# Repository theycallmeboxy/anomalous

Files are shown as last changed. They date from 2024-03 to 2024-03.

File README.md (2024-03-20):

# Anomalous Keyboard

## Features

- Integrated STM32 Microcontroller
  
- 42 Key Alice-ish Ortho Layout

- Red Dragon Low Profile Switches

- Solder Only

## Repository Contents

- `pcb/`: KiCAD and production files (bom is missing part numbers)

## Status

- Prototype 1 PCBs ordered 3/15/2024
- Prototype 1 PCBs received 3/20/2024

**DISCLAIMER: I'm not a doctor.  This is not medical advice.  I'm also only a network engineer.  You assume all liability in using or reproducing these files.**

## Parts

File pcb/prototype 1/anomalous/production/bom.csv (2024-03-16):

Designator | Footprint | Quantity | Value | LCSC Part #
BOOT1, RST1 | SW_SPST_TL3342 | 2 | SW_SPST
C1, C3, C4, C5, C6, C7, C8 | 0402 | 7 | 100nF | C307331
C10, C9 | 0402 | 2 | 1uF | C307331
C2 | 0603 | 1 | 10uF | C307331
D1, D10, D11, D12, D13, D14, D15, D16, D17, D18, D19, D2, D20, D21, D22, D23, D24, D25, D26, D27, D28, D29, D3, D30, D31, D32, D33, D34, D35, D36, D37, D38, D39, D4, D40, D41, D42, D5, D6, D7, D8, D9 | D_SOD-123 | 42 | D_Small
F1 | 1206 | 1 | 500mA | C135341
J1 | USB_C_Receptacle_HRO_TYPE-C-31-M-12 | 1 | USB_C_Receptacle_USB2.0
MX1, MX10, MX11, MX12, MX13, MX14, MX15, MX16, MX17, MX18, MX19, MX2, MX20, MX21, MX22, MX23, MX24, MX25, MX26, MX27, MX28, MX29, MX3, MX30, MX31, MX32, MX33, MX34, MX35, MX36, MX37, MX38, MX39, MX4, MX40, MX41, MX42, MX5, MX6, MX7, MX8, MX9 | SW_Redragon_LowProfile_PCB_1.00u-naked | 42 | MX_SW_solder
R1, R2, R3, R4 | 0402 | 4 | 5.1k
U1 | LQFP-48_7x7mm_P0.5mm | 1 | STM32F072CBT6
U2 | SOT-143 | 1 | PRTR5V0U2X | C2827688
U3 | SOT-23 | 1 | XC6206PxxxMR-Regulator_Linear | C5446

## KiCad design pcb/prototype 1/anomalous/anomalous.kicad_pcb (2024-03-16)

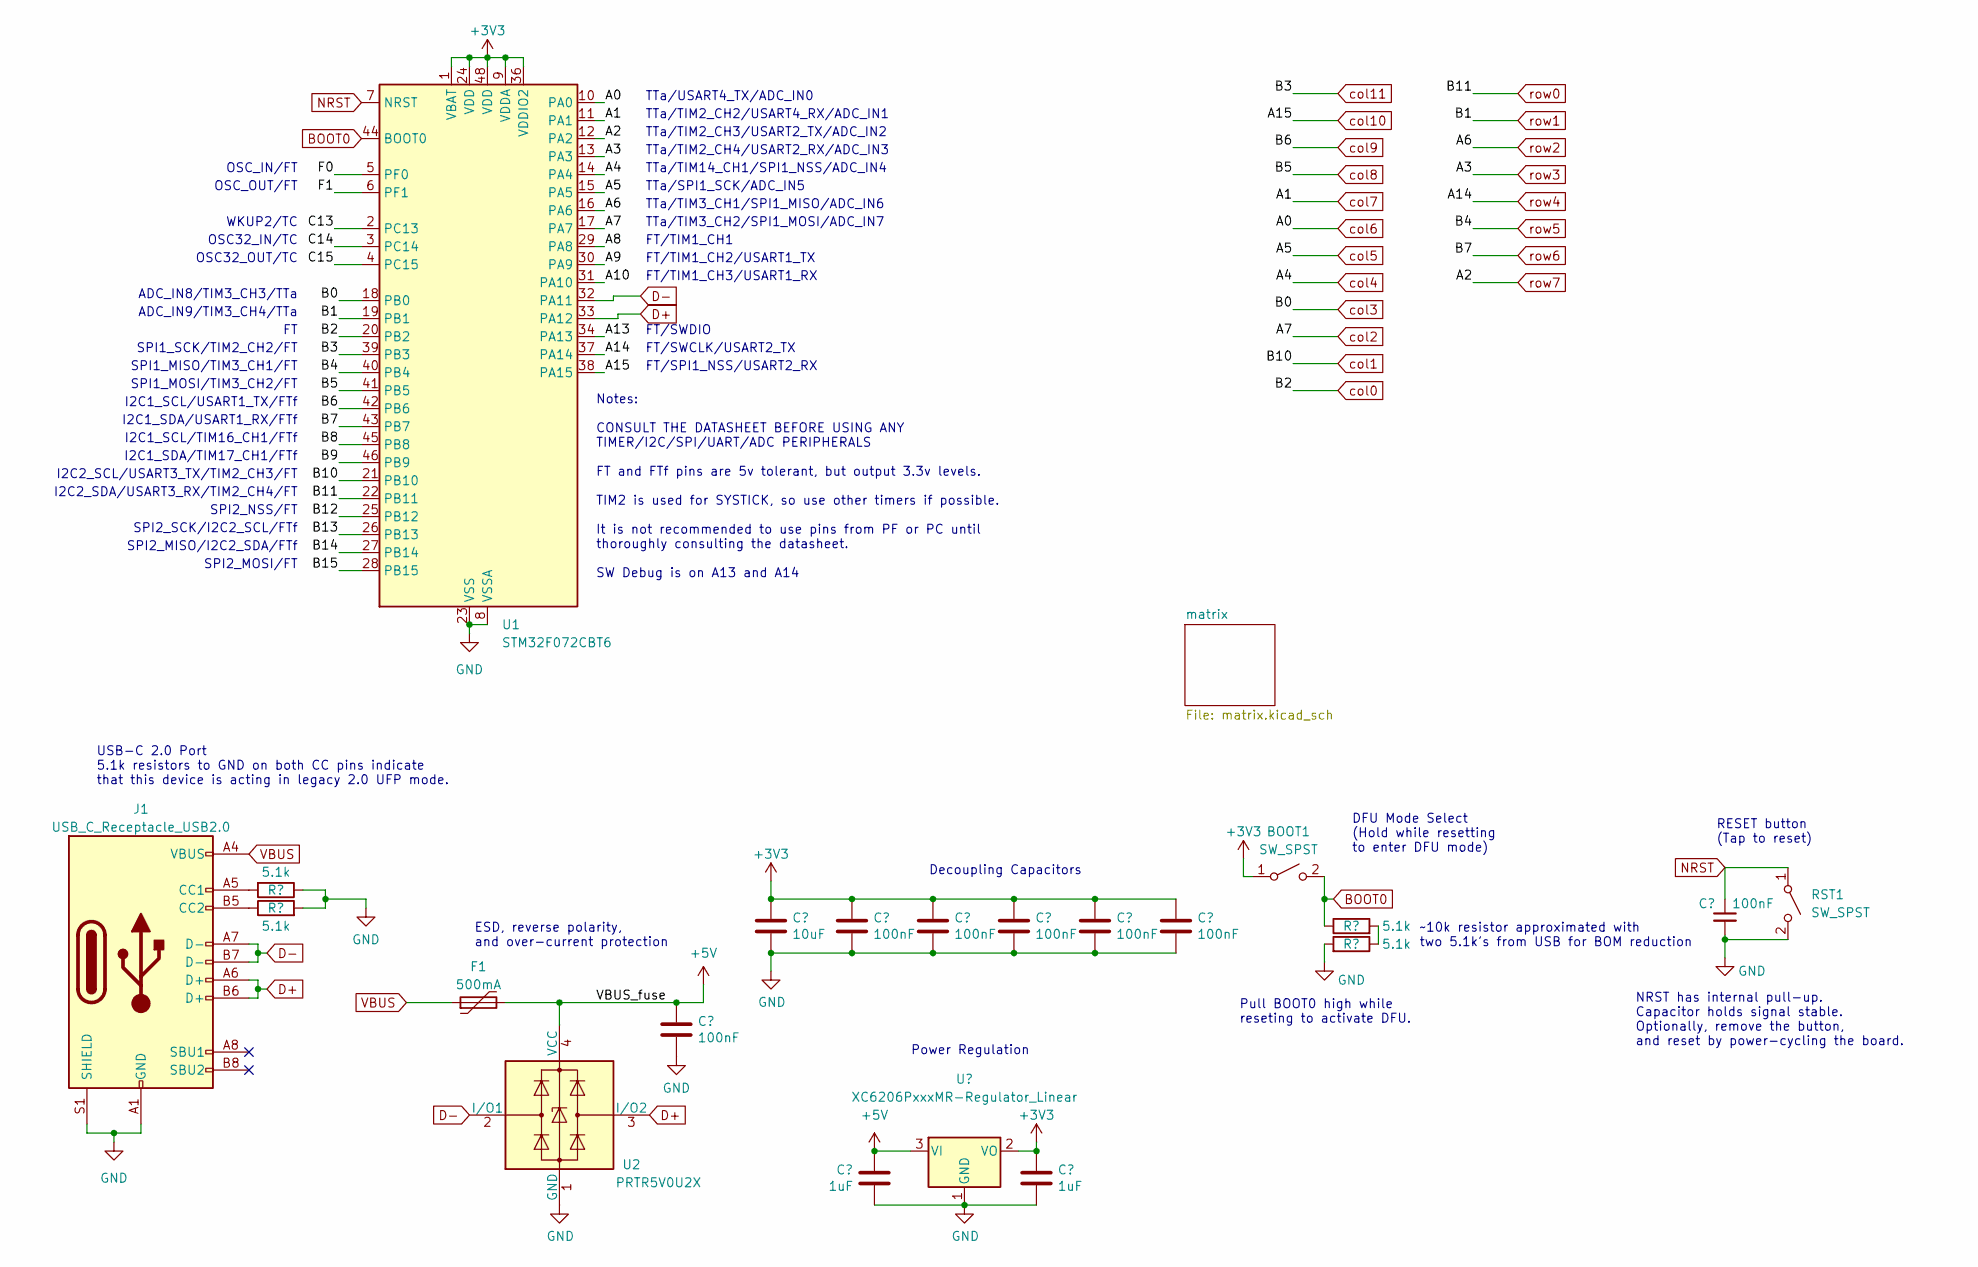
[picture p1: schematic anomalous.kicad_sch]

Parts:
BOOT1: SW_SPST; SW_SPST_TL3342
C1, C3, C4, C5, C6, C7, C8: 100nF; C_0402_1005Metric; LCSC C307331
C2: 10uF; C_0603_1608Metric; LCSC C307331
C9, C10: 1uF; C_0402_1005Metric; LCSC C307331
F1: 500mA; Fuse_1206_3216Metric; LCSC C135341
J1: USB_C_Receptacle_USB2.0; USB_C_Receptacle_HRO_TYPE-C-31-M-12; JlcRotOffset 180
R1, R2, R3, R4: 5.1k; R_0402_1005Metric
RST1: SW_SPST; SW_SPST_TL3342
U1: STM32F072CBT6; LQFP-48_7x7mm_P0.5mm; JlcRotOffset 90
U2: PRTR5V0U2X; SOT-143; LCSC C2827688
U3: XC6206PxxxMR-Regulator_Linear; SOT-23; LCSC C5446

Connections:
+3V3: BOOT1.1 (A), C2.1, C3.1, C4.1, C5.1, C6.1, C7.1, C10.1, U1.1 (VBAT), U1.9 (VDDA), U1.24 (VDD), U1.36 (VDDIO2), U1.48 (VDD), U3.2 (VO)
+5V: C8.1, C9.1, F1.2, U2.4 (VCC), U3.3 (VI)
/A8: U1.29 (PA8)
/A9: U1.30 (PA9)
/A10: U1.31 (PA10)
/A13: U1.34 (PA13)
/B8: U1.45 (PB8)
/B9: U1.46 (PB9)
/B12: U1.25 (PB12)
/B13: U1.26 (PB13)
/B14: U1.27 (PB14)
/B15: U1.28 (PB15)
/C13: U1.2 (PC13)
/C14: U1.3 (PC14)
/C15: U1.4 (PC15)
/F0: U1.5 (PF0)
/F1: U1.6 (PF1)
BOOT0: BOOT1.2 (B), R3.1, U1.44 (BOOT0)
D+: J1.A6 (D+), J1.B6 (D+), U1.33 (PA12), U2.3 (I/O2)
D-: J1.A7 (D-), J1.B7 (D-), U1.32 (PA11), U2.2 (I/O1)
GND: C1.2, C2.2, C3.2, C4.2, C5.2, C6.2, C7.2, C8.2, C9.2, C10.2, J1.A1 (GND), J1.A12 (GND), J1.B1 (GND), J1.B12 (GND), J1.S1 (SHIELD), R1.1, R2.2, R4.2, RST1.2 (B), U1.8 (VSSA), U1.23 (VSS), U1.35 (VSS), U1.47 (VSS), U2.1 (GND), U3.1 (GND)
NRST: C1.1, RST1.1 (A), U1.7 (NRST)
unnamed: J1.A5 (CC1), R1.2
unnamed: J1.B5 (CC2), R2.1
unnamed: R3.2, R4.1
VBUS: F1.1, J1.A4 (VBUS), J1.A9 (VBUS), J1.B4 (VBUS), J1.B9 (VBUS)
col0: U1.20 (PB2); also elsewhere on the board
col1: U1.21 (PB10); also elsewhere on the board
col2: U1.17 (PA7); also elsewhere on the board
col3: U1.18 (PB0); also elsewhere on the board
col4: U1.14 (PA4); also elsewhere on the board
col5: U1.15 (PA5); also elsewhere on the board
col6: U1.10 (PA0); also elsewhere on the board
col7: U1.11 (PA1); also elsewhere on the board
col8: U1.41 (PB5); also elsewhere on the board
col9: U1.42 (PB6); also elsewhere on the board
col10: U1.38 (PA15); also elsewhere on the board
col11: U1.39 (PB3); also elsewhere on the board
row0: U1.22 (PB11); also elsewhere on the board
row1: U1.19 (PB1); also elsewhere on the board
row2: U1.16 (PA6); also elsewhere on the board
row3: U1.13 (PA3); also elsewhere on the board
row4: U1.37 (PA14); also elsewhere on the board
row5: U1.40 (PB4); also elsewhere on the board
row6: U1.43 (PB7); also elsewhere on the board
row7: U1.12 (PA2); also elsewhere on the board

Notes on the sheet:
SPI1_SCK/TIM2_CH2/FT
FT/TIM1_CH1
FT/TIM1_CH3/USART1_RX
SPI2_NSS/FT
Notes: CONSULT THE DATASHEET BEFORE USING ANY TIMER/I2C/SPI/UART/ADC PERIPHERALS FT and FTf pins are 5v tolerant, but output 3.3v levels. TIM2 is used for SYSTICK, so use other timers if possible. It is not recommended to use pins from PF or PC until thoroughly consulting the datasheet. SW Debug is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
TTa/TIM2_CH4/USART2_RX/ADC_IN3
NRST has internal pull-up. Capacitor holds signal stable. Optionally, remove the button, and reset by power-cycling the board.
FT/SWDIO
Decoupling Capacitors
SPI1_MOSI/TIM3_CH2/FT
ADC_IN9/TIM3_CH4/TTa
I2C2_SCL/USART3_TX/TIM2_CH3/FT
SPI2_MISO/I2C2_SDA/FTf
FT/SWCLK/USART2_TX
I2C1_SCL/TIM16_CH1/FTf
~10k resistor approximated with two 5.1k's from USB for BOM reduction
TTa/TIM2_CH2/USART4_RX/ADC_IN1
USB-C 2.0 Port 5.1k resistors to GND on both CC pins indicate that this device is acting in legacy 2.0 UFP mode.
TTa/TIM2_CH3/USART2_TX/ADC_IN2
OSC_IN/FT
DFU Mode Select (Hold while resetting to enter DFU mode)
WKUP2/TC
I2C2_SDA/USART3_RX/TIM2_CH4/FT
ADC_IN8/TIM3_CH3/TTa
RESET button (Tap to reset)
Pull BOOT0 high while reseting to activate DFU.
I2C1_SDA/TIM17_CH1/FTf
TTa/SPI1_SCK/ADC_IN5
TTa/TIM3_CH1/SPI1_MISO/ADC_IN6
TTa/TIM3_CH2/SPI1_MOSI/ADC_IN7
OSC32_OUT/TC
FT/SPI1_NSS/USART2_RX
SPI1_MISO/TIM3_CH1/FT
OSC32_IN/TC
TTa/TIM14_CH1/SPI1_NSS/ADC_IN4
I2C1_SDA/USART1_RX/FTf
SPI2_MOSI/FT
FT/TIM1_CH2/USART1_TX
Power Regulation
SPI2_SCK/I2C2_SCL/FTf

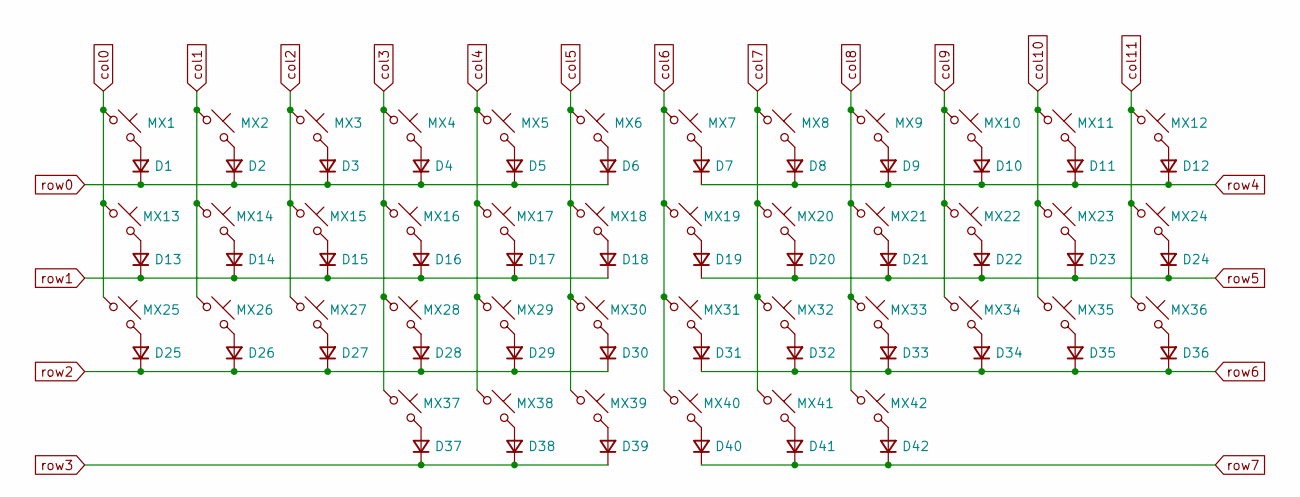
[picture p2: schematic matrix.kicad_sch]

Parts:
D1, D2, D3, D4, D5, D6, D7, D8, D9, D10, D11, D12, D13, D14, D15, D16, D17, D18, D19, D20, D21, D22, D23, D24, D25, D26, D27, D28, D29, D30, D31, D32, D33, D34, D35, D36, D37, D38, D39, D40, D41, D42: D_Small; D_SOD-123
MX1, MX2, MX3, MX4, MX5, MX6, MX7, MX8, MX9, MX10, MX11, MX12, MX13, MX14, MX15, MX16, MX17, MX18, MX19, MX20, MX21, MX22, MX23, MX24, MX25, MX26, MX27, MX28, MX29, MX30, MX31, MX32, MX33, MX34, MX35, MX36, MX37, MX38, MX39, MX40, MX41, MX42: MX_SW_solder; SW_Redragon_LowProfile_PCB_1.00u

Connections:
unnamed: D1.2 (A), MX1.2
unnamed: D2.2 (A), MX2.2
unnamed: D3.2 (A), MX3.2
unnamed: D4.2 (A), MX4.2
unnamed: D5.2 (A), MX5.2
unnamed: D6.2 (A), MX6.2
unnamed: D7.2 (A), MX7.2
unnamed: D8.2 (A), MX8.2
unnamed: D9.2 (A), MX9.2
unnamed: D10.2 (A), MX10.2
unnamed: D11.2 (A), MX11.2
unnamed: D12.2 (A), MX12.2
unnamed: D13.2 (A), MX13.2
unnamed: D14.2 (A), MX14.2
unnamed: D15.2 (A), MX15.2
unnamed: D16.2 (A), MX16.2
unnamed: D17.2 (A), MX17.2
unnamed: D18.2 (A), MX18.2
unnamed: D19.2 (A), MX19.2
unnamed: D20.2 (A), MX20.2
unnamed: D21.2 (A), MX21.2
unnamed: D22.2 (A), MX22.2
unnamed: D23.2 (A), MX23.2
unnamed: D24.2 (A), MX24.2
unnamed: D25.2 (A), MX25.2
unnamed: D26.2 (A), MX26.2
unnamed: D27.2 (A), MX27.2
unnamed: D28.2 (A), MX28.2
unnamed: D29.2 (A), MX29.2
unnamed: D30.2 (A), MX30.2
unnamed: D31.2 (A), MX31.2
unnamed: D32.2 (A), MX32.2
unnamed: D33.2 (A), MX33.2
unnamed: D34.2 (A), MX34.2
unnamed: D35.2 (A), MX35.2
unnamed: D36.2 (A), MX36.2
unnamed: D37.2 (A), MX37.2
unnamed: D38.2 (A), MX38.2
unnamed: D39.2 (A), MX39.2
unnamed: D40.2 (A), MX40.2
unnamed: D41.2 (A), MX41.2
unnamed: D42.2 (A), MX42.2
col0: MX1.1, MX13.1, MX25.1; also elsewhere on the board
col1: MX2.1, MX14.1, MX26.1; also elsewhere on the board
col2: MX3.1, MX15.1, MX27.1; also elsewhere on the board
col3: MX4.1, MX16.1, MX28.1, MX37.1; also elsewhere on the board
col4: MX5.1, MX17.1, MX29.1, MX38.1; also elsewhere on the board
col5: MX6.1, MX18.1, MX30.1, MX39.1; also elsewhere on the board
col6: MX7.1, MX19.1, MX31.1, MX40.1; also elsewhere on the board
col7: MX8.1, MX20.1, MX32.1, MX41.1; also elsewhere on the board
col8: MX9.1, MX21.1, MX33.1, MX42.1; also elsewhere on the board
col9: MX10.1, MX22.1, MX34.1; also elsewhere on the board
col10: MX11.1, MX23.1, MX35.1; also elsewhere on the board
col11: MX12.1, MX24.1, MX36.1; also elsewhere on the board
row0: D1.1 (K), D2.1 (K), D3.1 (K), D4.1 (K), D5.1 (K), D6.1 (K); also elsewhere on the board
row1: D13.1 (K), D14.1 (K), D15.1 (K), D16.1 (K), D17.1 (K), D18.1 (K); also elsewhere on the board
row2: D25.1 (K), D26.1 (K), D27.1 (K), D28.1 (K), D29.1 (K), D30.1 (K); also elsewhere on the board
row3: D37.1 (K), D38.1 (K), D39.1 (K); also elsewhere on the board
row4: D7.1 (K), D8.1 (K), D9.1 (K), D10.1 (K), D11.1 (K), D12.1 (K); also elsewhere on the board
row5: D19.1 (K), D20.1 (K), D21.1 (K), D22.1 (K), D23.1 (K), D24.1 (K); also elsewhere on the board
row6: D31.1 (K), D32.1 (K), D33.1 (K), D34.1 (K), D35.1 (K), D36.1 (K); also elsewhere on the board
row7: D40.1 (K), D41.1 (K), D42.1 (K); also elsewhere on the board

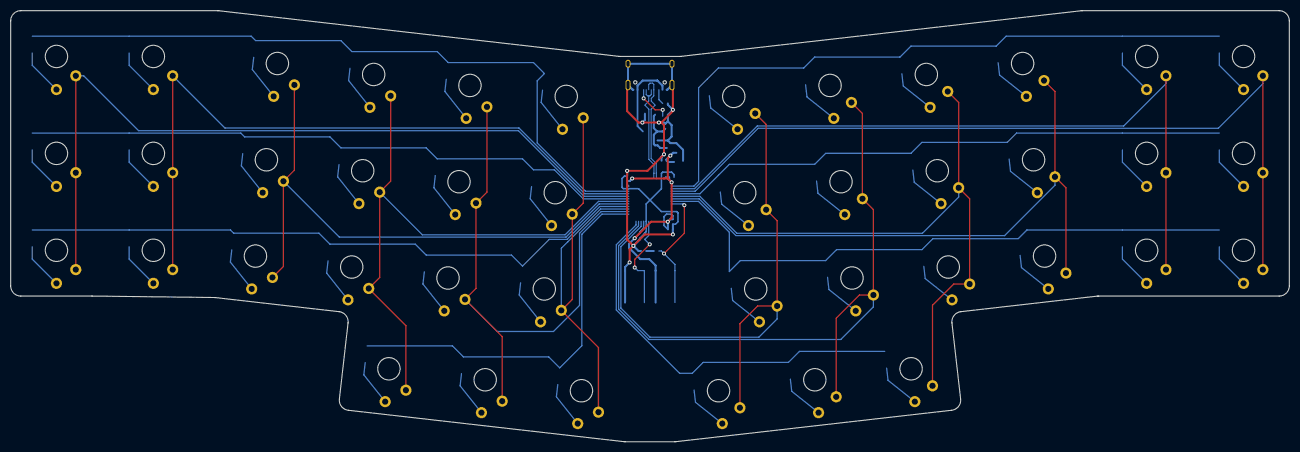
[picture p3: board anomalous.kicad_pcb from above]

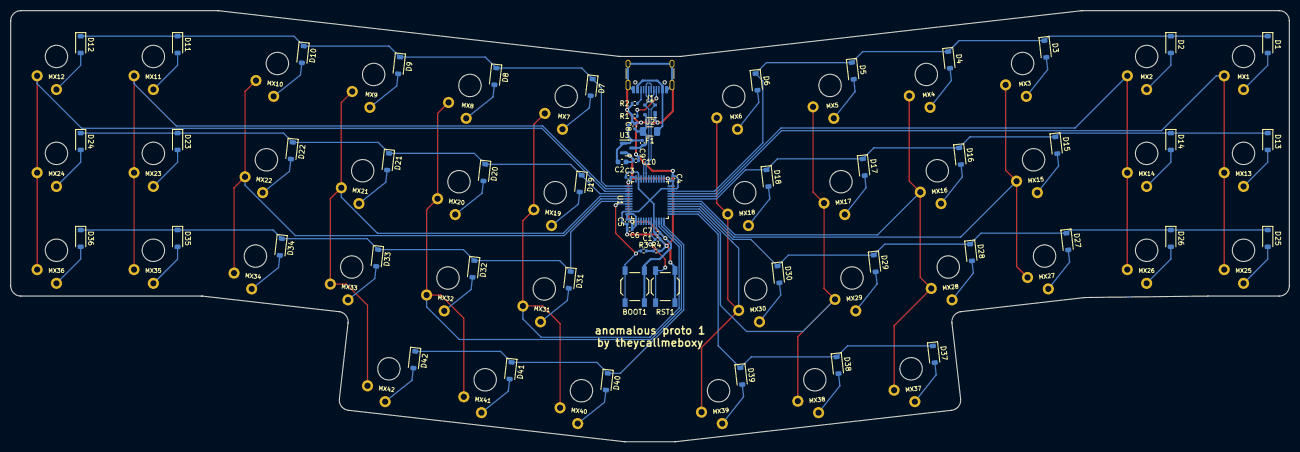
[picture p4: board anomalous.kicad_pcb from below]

Board: 2 copper layers, 251.4 x 84.7 mm, 105 parts (63 on the bottom side), 73 nets.
